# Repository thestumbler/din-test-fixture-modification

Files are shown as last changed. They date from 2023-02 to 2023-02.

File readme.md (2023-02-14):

# Wedge to Modify 3D Printed DIN Rail Test Stand

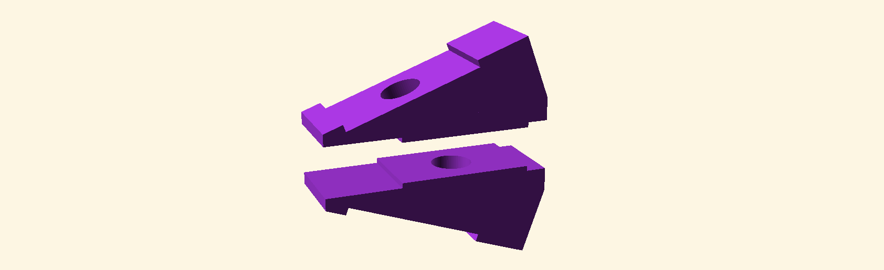
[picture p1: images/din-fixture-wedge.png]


### Background

As seen in the picture below, user PlasticXYZ made a clever DIN rail
test stand for benchtop use in the lab. Their design files are available
at Printables (_see link at the bottom, image from PlasticXYZ_).

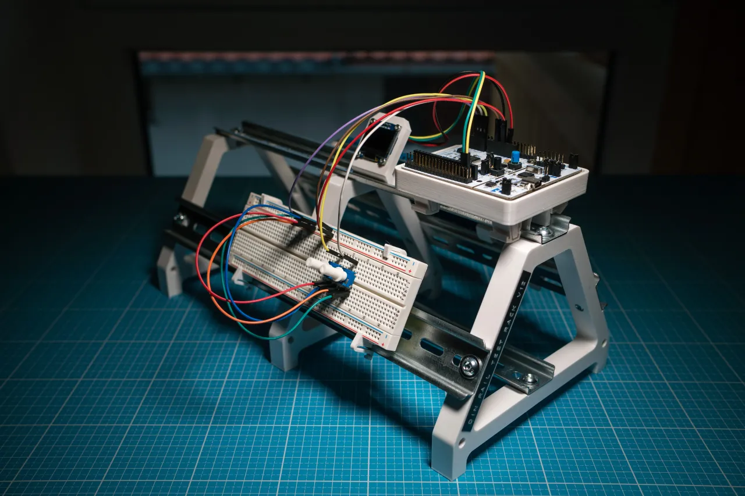
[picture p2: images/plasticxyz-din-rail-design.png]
Printables DIN RAIL TEST RACK by PlasticXYZ


I printed and assembled my test rack using 500 mm pre-cut lengths of DIN rail.
Since the bottom rail is a little hard to access, I planned to put terminal blocks on that rail.
These would be used for power distribution and rarely need to be accessed.

### Problem

Unfortunately, things mounted on the bottom rail are very hard to access by screwdriver, 
because the top rail blocks access. I decided to modify the design slightly and put the bottom rail at a
slight angle, thus allowing easier access. After poking around in
OpenSCAD, the magic angle works out to be 20 degrees. As depicted by 
the big orange cube the sketch, this should be perfect.

<!-- 
![Sketch showing screwdriver access](images/din-fixture.png)
-->
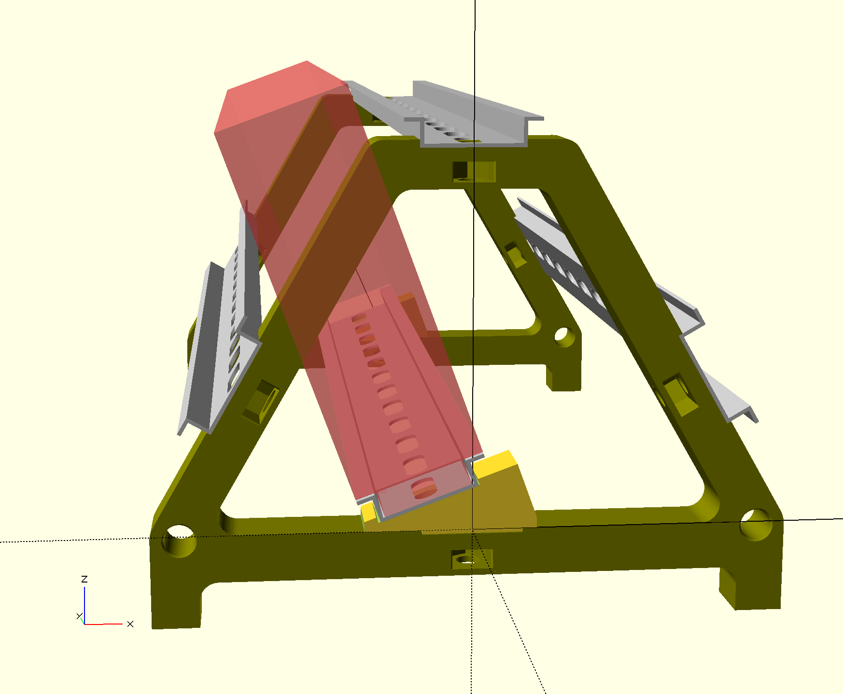
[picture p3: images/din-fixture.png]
Sketch showing screwdrive access


### Solution

The original source files aren't available, so I decided not to try to
reconstruct the triangular brackets. That would have also required
re-printing them, a non-trivial amount of time for such a small change.
Instead, I made a small wedge-shaped piece that holds the bottom rail at
the 20 degree angle and attaches to the brackets as originally designed.

Since the wedge needs to be small, I couldn't use the captive square nut
approach as Plastic XYZ did. Instead, I used M5 threaded brass inserts,
which I pressed into the wedge after printing. 

**NOTE:** This modification is still underway. I will post photos later of the finished product. 

### Files

* `din-fixture.scad` Contains the wedge and a render of the entire assembly.
* `din-fixture-wedge.stl` Wedge STL file
* `din-test-fixture-triangle-support.stl` Original bracket STL file from PlasticXYZ

### Printables link to PlasticXYZ's design:

[https://www.printables.com/model/150786-din-rail-test-rack](https://www.printables.com/model/150786-din-rail-test-rack/comments)

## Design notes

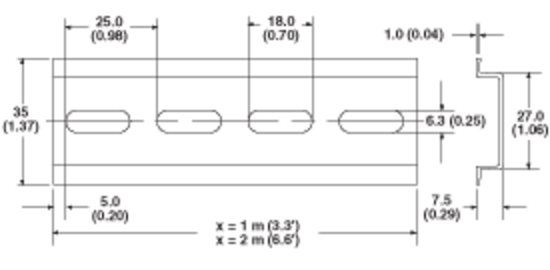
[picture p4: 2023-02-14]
images/rail-dims.png

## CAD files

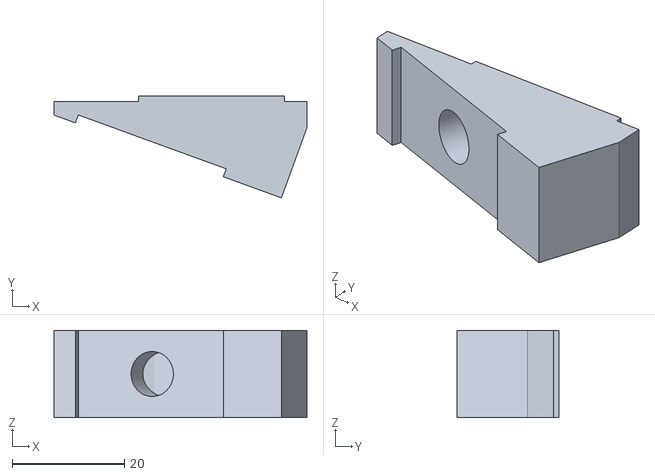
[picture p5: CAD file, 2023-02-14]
din-fixture-wedge.stl
45.0 x 18.1 x 15.5

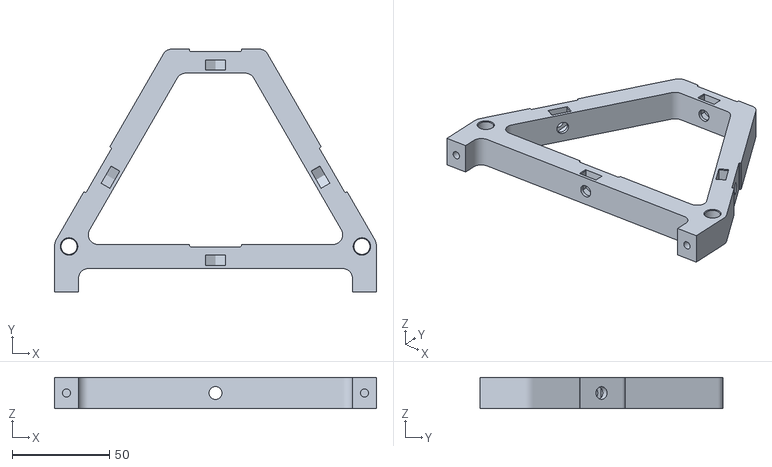
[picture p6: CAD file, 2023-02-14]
din-test-fixture-triangle-support.stl
165.8 x 125.0 x 16.0

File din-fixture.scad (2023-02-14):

include <lib.scad>



hole = 4; //hole diamter
rail_thk = 1.0;
rail_base = 27;
rail_hgt = 7.5;
rail_wid = 35;
rail_lip = 0.5 * (rail_wid - rail_base) + rail_thk;
slot_len = 18.0;
slot_wid = 6.3;
slot_c2c = 25.0;
slot_gap = slot_c2c - slot_len;
slot_hole_c2c = slot_len - slot_wid;
module make_din_rail( length ) {
  color("silver") {
  // draw the edges and lips
  translate([rail_hgt-rail_thk,0.5*rail_base-rail_thk,0]) 
    cube([rail_thk,rail_lip,length]);
  translate([0,0.5*rail_base-rail_thk,0]) 
    cube([rail_hgt,rail_thk,length]);;
  mirror([0,1,0]) {
    translate([rail_hgt-rail_thk,0.5*rail_base-rail_thk,0]) 
      cube([rail_thk,rail_lip,length]);
    translate([0,0.5*rail_base-rail_thk,0]) 
      cube([rail_hgt,rail_thk,length]);;
  }

  difference() {
    // base rail
    translate([0,-0.5*rail_base,0]) 
      cube([rail_thk,rail_base,length]);
    // holes
    for(z= [0:slot_c2c:length-0.5*slot_gap]) {
      translate([-0.5*rail_thk,0,z+0.5*slot_wid+0.5*slot_gap])
      rotate([0,90,0])  
      hull() {
        translate([-slot_hole_c2c,0,0])
          cylinder(h=2*rail_thk,d=slot_wid, $fn=30);
        cylinder(h=2*rail_thk,d=slot_wid, $fn=30);
      }
    }  
  }
  }
}

module place_din_rail(length=100) {
  rotate(-90,[1,0,0])
  rotate(-90,[0,0,1])
  make_din_rail(length);
}

module place_din_rail_access(length=100) {
  rail_box2 = [ rail_base-3*rail_thk, length, rail_hgt];
  translate([-0.5*rail_wid,0,rail_hgt+0.5])
  #cube( [rail_wid, length, 100] );
  translate([-0.5*rail_box2.x,0,rail_thk])
  #cube( rail_box2 );
}

bkt_off = 23;
bkt_thk = 16;
bkt_hgt = 100;
bkt_recess = 1.4;

wedge=[50,bkt_thk-0.5,25];
din_proud=[26,wedge.y,1.0];
din_recess=[28,10+wedge.y,2];
wedge_ang = 20;
m5_insert_deep = 5;
m5_insert_dia = 8;
module make_wedge() {
  difference() {
    union() {
      // sloping wedge
      translate([-0.735*wedge.x*cos(wedge_ang),0,0]) // 0.735 positions rail along the wedge slope 
        rotate(-wedge_ang,[0,1,0]) {
          translate([0,0,-wedge.z])
            difference() {
              cube(wedge);
              // m5 brass insert, _deep-xxx is additional depth of brass insert hole
              translate([0.5*wedge.x,0.5*wedge.y,wedge.z-m5_insert_deep-1.3-din_recess.z])
                cylinder(h=20,d=m5_insert_dia);
              // din rail recess
              translate([0.5*(wedge.x-din_recess.x),
                         0.5*(wedge.y-din_recess.y),wedge.z-1.5])
                cube(din_recess);
            }
        }
      // DIN rail protrusion
      translate([-0.5*din_proud.x,0,-din_proud.z+0.01])
        cube(din_proud);
    }
    // trim bottom
    translate([0.5*din_proud.x,-5,-30])
      cube([100,100,30]);
    translate([-100-0.5*din_proud.x,-5,-30])
      cube([100,100,30]);
    translate([-50,-5,-30-1])
      cube([100,25,30]);
    // trim ends
    translate([17,-10+0.5*wedge.y,-0.5])
      cube([20,20,50]);
    translate([-20-28,-10+0.5*wedge.y,-0.5])
      cube([20,20,50]);
    // m5 brass insert, _deep+xxx is additional depth of brass insert hole
    translate([0,0.5*wedge.y,-din_proud.z-0.01])
      cylinder(h=m5_insert_deep+4.5,d=m5_insert_dia);
  }
}
module make_wedge_cutaway() {
  // used to adjust depth of m5 insert holes
  difference() { // cut away
    make_wedge();
    translate([0,4,0])
      cube([100,10,100],center=true);
  }
}
module print_wedge() {
// has to be printed on its side
// because of din rail protrusion on the bottom
rotate(90,[1,0,0])
  make_wedge();
}
module draw_wedge() {
  // make pretty view of wedge for readme
  sep=5;
  color("darkorchid") {
    translate([0, -0.5*wedge.y,sep])
    make_wedge();
    translate([0, 0.5*wedge.y,-sep])
    rotate(180,[1,0,0])
    make_wedge();
  }
}



module make_bracket(slice=false) {
  cut = [300,300,40];
  color("olive")
  translate([0,bkt_thk+0.01,0])
  rotate(90,[1,0,0])
  difference() {
    translate([0,-bkt_off-bkt_recess,0.5*bkt_thk])
      import("din-test-fixture-triangle-support.stl");
    if(slice) {
      translate([-0.5*cut.x, 25, -0.25*cut.z])
        cube(cut);
    }
  }
}


module make_assy() {
  make_bracket();
  make_wedge();
  translate([0,300-bkt_thk,0]) {
    make_bracket();
    make_wedge();
  }

  // bottom anguled rail
  translate([-11,-0.01,7])
    rotate(-wedge_ang,[0,1,0]) {
      place_din_rail(300);
      place_din_rail_access(300);
    }

  din_angle = 60;
  // top din rail
  translate([0,0,bkt_hgt-bkt_recess]) place_din_rail(300);

  translate([-60.0,0,38.3])
    rotate(-din_angle,[0,1,0])
      place_din_rail(300);

  translate([60.0,0,38.3])
    rotate(din_angle,[0,1,0])
      place_din_rail(300);
}

// make_assy();
// print_wedge();
// draw_wedge();
make_wedge();
